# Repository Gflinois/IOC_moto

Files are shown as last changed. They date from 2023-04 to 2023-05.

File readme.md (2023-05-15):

# Motorcycle Sensor Network

This Git project contains the code for a network of sensors connected to a Raspberry Pi that collects data from a motorcycle and displays it on a webpage. The sensors include:

- thermistance for monitoring the heat of the engine
- lumistance for measuring light (by connecting a relay you can automate headlights)
- IMU for measuring acceleration and speed in all directions (interraction with website not ready yet because we have no non broken IMU yet)
- Tachimeter spying for RPM monitoring

The project also include an OLED output for ESP32, actually the esp32 used with the thermistance is receiving the lumistance value from the raspberry pi.

## Requirements

To use this code, you will need:

- Raspberry Pi 3 or later
- Python 3
- the python libraries shown in the dedicated file
- lumistance
- thermistance
- IMU sensor
- cables to divert the tachimeter's tension
- one esp32 by sensor with ble capability (exept for the IMU which's code is currently being developped for an arduino pro micro)

## Installation

1. Clone this Git repo's server file to your Raspi
2. Install the required Python packages on the Raspberry by running `pip3 install -r requirements.txt`
3. Install the BLE library on the ESPs (respectively arduino pro micro)
4. Install the driver for the correct sensor on the esp32s (respectively arduino pro micro)
5. Start the web server by running `python3 web.py`
6. Start the communication with the ESPs by using `python3 bleservice.py`

## Usage

After installing everything and instaling the sensors on the motorcycle , whatch the magic by connecting to the local server oppened by the raspberry.

### Contribution

Contributions to this Git project are welcome! Please submit pull requests to the `dev` branch and include a detailed description of your changes.

## License

This project is licensed under the MIT License. See the `LICENSE` file for details.

## Easter-egg for the ones that are working on a XJ400 (or that are having airbox issues)

Since airboxes are no longer available on the market for xj400 and as you may know this model is verry tightly packed I designed a 3D printable servicable low profile airbox in BAA. If anyone wants to build it please do, stl cad and gcode for an ender 3 pro are available. If anyone is interested in a simple airbox but for another model please try to modify my design and upload it here, I will be available to help you finish the work if need be.

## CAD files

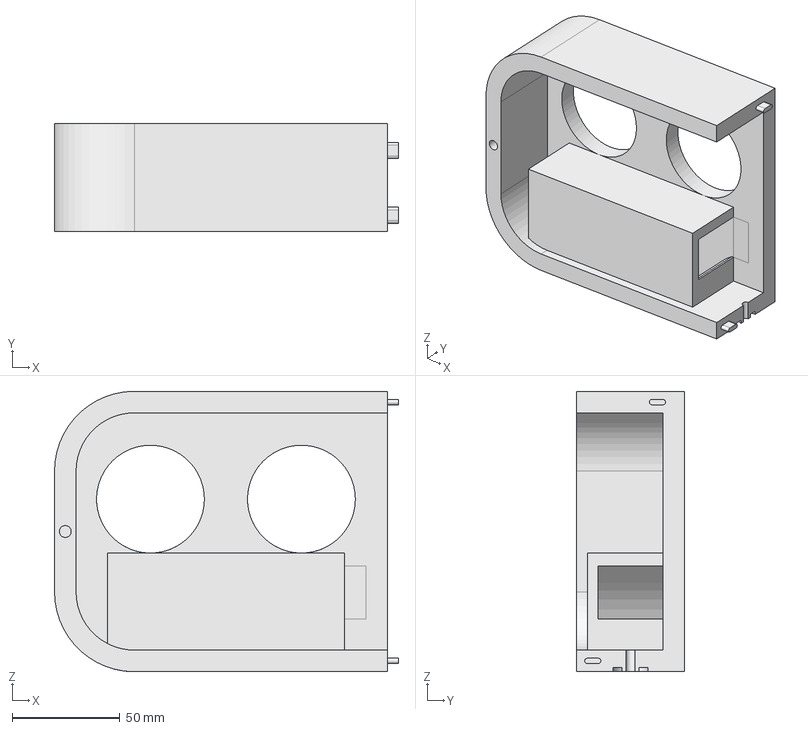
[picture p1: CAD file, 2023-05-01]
baa/cad/boite_a_air_L.FCStd
159.5 x 50.0 x 130.0 mm

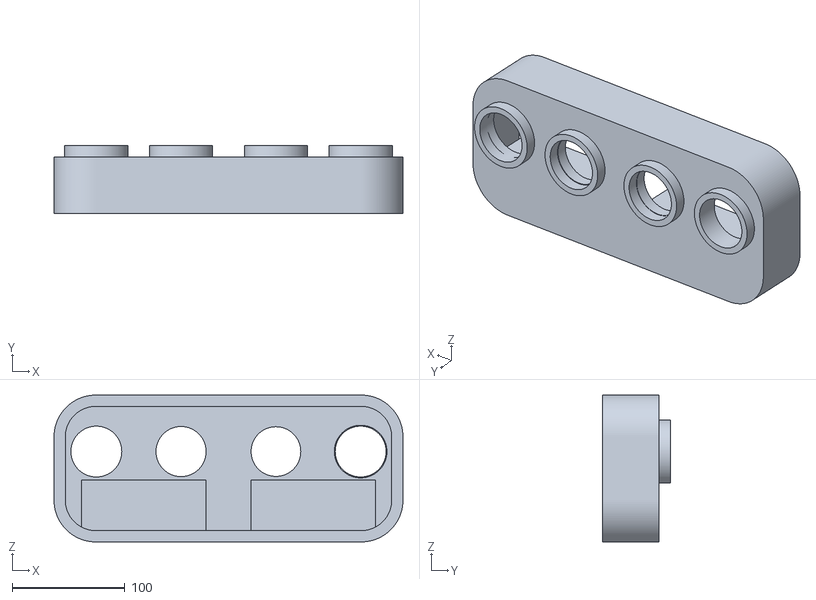
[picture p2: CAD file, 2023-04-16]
baa/stl/boite_a_air_tot.stl
309.0 x 60.0 x 130.0

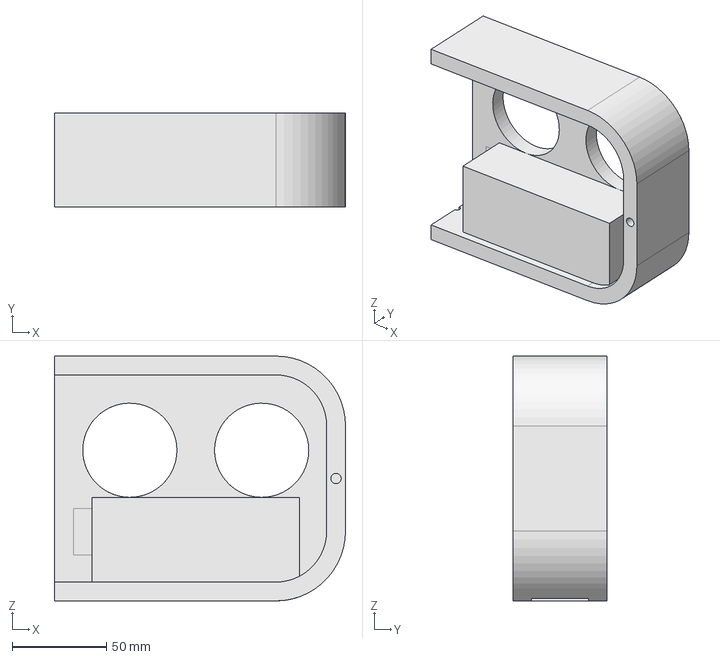
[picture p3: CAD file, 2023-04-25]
baa/cad/boite_a_air_R.FCStd
154.5 x 50.0 x 130.0 mm

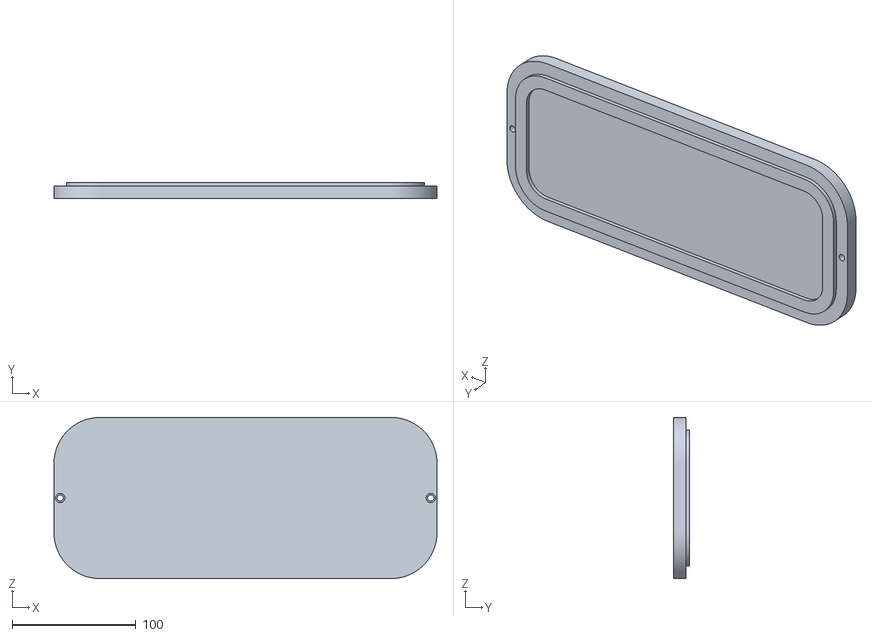
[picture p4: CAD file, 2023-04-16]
baa/stl/couvercle_tot.stl
309.0 x 13.0 x 130.0

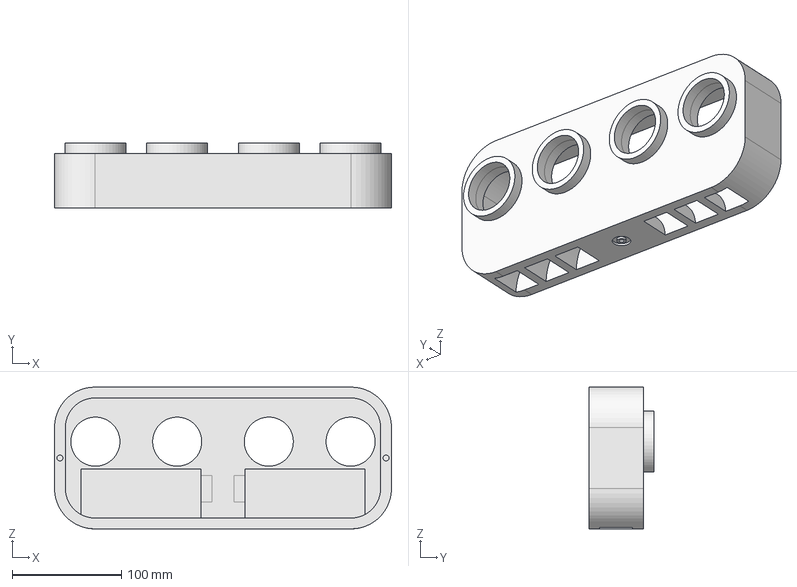
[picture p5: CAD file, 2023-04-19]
baa/cad/boite_a_air_thin.FCStd
309.0 x 60.0 x 130.0 mm

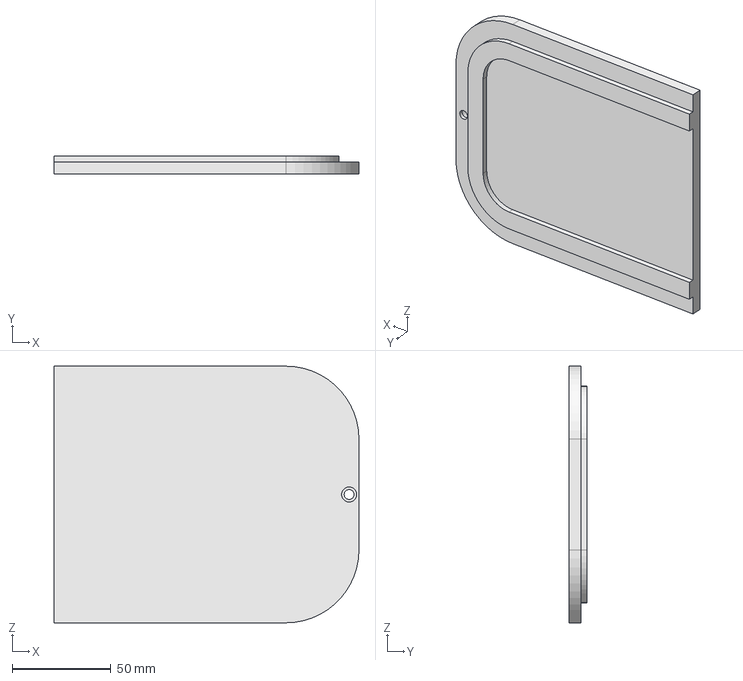
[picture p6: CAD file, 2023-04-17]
baa/cad/couvercle_R.FCStd
154.5 x 9.00 x 130.0 mm

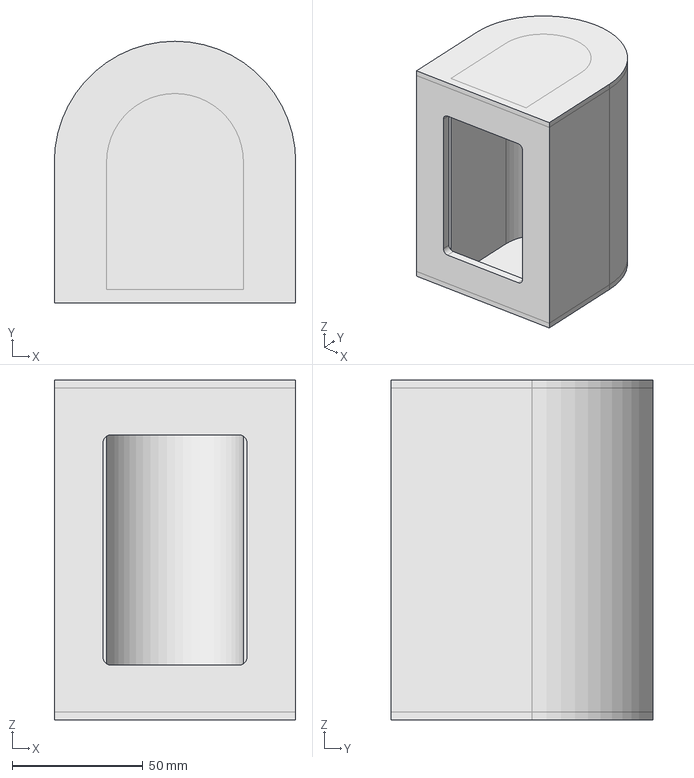
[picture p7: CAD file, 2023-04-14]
baa/cad/filtre.FCStd
92.3 x 100.0 x 130.0 mm

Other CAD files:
baa/cad/couvercle_L.FCStd
baa/cad/couvercle.FCStd
baa/stl/boite_a_air_L.stl
baa/stl/boite_a_air_R.stl
baa/stl/couvercle_L.stl
baa/stl/couvercle_R.stl

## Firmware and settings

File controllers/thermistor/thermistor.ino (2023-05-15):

#include <Adafruit_SSD1306.h>
#include <Adafruit_GFX.h>
#include <Wire.h>

#include <BLEDevice.h>
#include <BLEServer.h>
#include <BLEUtils.h>

// -----------------------------------------------------------------
// OLED CONFIG 
// -----------------------------------------------------------------

#define SCREEN_WIDTH 128 // OLED display width, in pixels
#define SCREEN_HEIGHT 64 // OLED display height, in pixels

#define OLED_RESET     16    // Reset pin # (or -1 if sharing Arduino reset pin)
#define SCREEN_ADDRESS 0x3C ///< See datasheet for Address; 0x3D for 128x64, 0x3C for 128x32

Adafruit_SSD1306 display(SCREEN_WIDTH, SCREEN_HEIGHT, &Wire, OLED_RESET);

// -----------------------------------------------------------------
// BLE CONFIG 
// -----------------------------------------------------------------

#define BLE_NAME                "MSN Thermistor"

// https://www.uuidgenerator.net/
#define TR_SERVICE_UUID         "0e4be5c8-b76c-4590-8eeb-35b93104c63e"
#define TR_CHARACTERISTIC_UUID  "177d03bb-a953-4f16-aabf-5246fbb3f72e"

#define PR_SERVICE_UUID         "f9e8c98a-0d57-423c-8ebc-ec69437c1c99"
#define PR_CHARACTERISTIC_UUID  "0dcdd589-bd02-42a5-b9c8-973ac9331c53"

#define THERMISTOR_PIN   36

char glbTrValue[32];
BLECharacteristic *glbTrCharacteristic;

char glbPrValue[32];
BLECharacteristic *glbPrCharacteristic;

bool deviceConnected = false;
bool advertising = false;

class ServerConnectCallback: public BLEServerCallbacks {
  void onConnect(BLEServer* pServer) {
    Serial.println("device connected");
    deviceConnected = true;
    advertising = false;
  };
  void onDisconnect(BLEServer* pServer) {
    Serial.println("device disconnected");
    deviceConnected = false;
  }
};

// -----------------------------------------------------------------
// TASK CONFIG 
// -----------------------------------------------------------------
#define MAX_WAIT_FOR_TIMER 2
unsigned int waitFor(int timer, unsigned long period){
  static unsigned long waitForTimer[MAX_WAIT_FOR_TIMER];  
  
  unsigned long newTime = micros() / period;
  int delta = newTime - waitForTimer[timer];
  
  if (delta < 0) 
    delta = 1 + newTime;
  
  if (delta)
    waitForTimer[timer] = newTime;
  
  return delta;
}

struct screen_refresh_s {
  int timer;
  int period;
};
struct screen_refresh_s screen_refresh_ctx;

void setup_screen_refresh(struct screen_refresh_s *ctx, int timer, int period) {
  ctx->timer = timer;
  ctx->period = period;
}

void loop_screen_refresh(struct screen_refresh_s *ctx) {
  if (!waitFor(ctx->timer, ctx->period)) return;
  Serial.println("screen refresh");
  if (deviceConnected) Serial.println("device connected: 1");
  else Serial.println("device connected: 0");
  if (advertising) Serial.println("advertising: 1");
  else Serial.println("advertising: 0");
  
  display.clearDisplay();
  display.setCursor(0, 0);

  display.println(BLE_NAME);
  display.println(F("BLE: on"));
  if (advertising)
    display.println(F("Status: advertising"));
  else
    display.println(F("Status: connected"));

  display.println();
  display.print("Lightning: ");
  display.print(glbPrCharacteristic->getValue().c_str());
  display.display();
}

// -----------------------------------------------------------------
// Main program 
// -----------------------------------------------------------------

void setup() {
  // ------------------------
  // Serial setup 
  // ------------------------
  Serial.begin(9600);
  Serial.println("starting ble services ...");

  // ------------------------
  // OLED setup 
  // ------------------------
  Wire.begin(4, 15);

  // SSD1306_SWITCHCAPVCC = generate display voltage from 3.3V internally
  if(!display.begin(SSD1306_SWITCHCAPVCC, SCREEN_ADDRESS)) {
    Serial.println(F("SSD1306 allocation failed"));
    for(;;); // Don't proceed, loop forever
  }
  display.clearDisplay();
  display.setTextSize(1);                     // Normal 1:1 pixel scale
  display.setTextColor(SSD1306_WHITE);        // Draw white text
  display.setCursor(0,0);                     // Start at top-left corner

  setup_screen_refresh(&screen_refresh_ctx, 0, 100000);

  // ------------------------
  // BLE setup 
  // ------------------------

  // Setup BLE peripheral (GATT server)
  BLEDevice::init(BLE_NAME);
  BLEServer *pServer = BLEDevice::createServer();
  pServer->setCallbacks(new ServerConnectCallback());
  BLEService *pRService = pServer->createService(TR_SERVICE_UUID);
  BLEService *pWService = pServer->createService(PR_SERVICE_UUID);
  
  // Initialize main characteristic (output)
  glbTrCharacteristic = pRService->createCharacteristic(
    TR_CHARACTERISTIC_UUID, BLECharacteristic::PROPERTY_READ);
  strncpy(glbTrValue, "0.0", 3);
  glbTrCharacteristic->setValue(glbTrValue);

  // Initialize secondary characteristic (input)
  glbPrCharacteristic = pWService->createCharacteristic(
    PR_CHARACTERISTIC_UUID, BLECharacteristic::PROPERTY_WRITE | BLECharacteristic::PROPERTY_READ);
  strncpy(glbPrValue, "?", 1);
  glbPrCharacteristic->setValue(glbPrValue);

  // Start the service
  pRService->start();
  pWService->start();
  
  // Setup & start ble ardvertising (pinging centrals)
  BLEAdvertising *pAdvertising = BLEDevice::getAdvertising();
  pAdvertising->addServiceUUID(TR_SERVICE_UUID);
  pAdvertising->addServiceUUID(PR_SERVICE_UUID);
  pAdvertising->setScanResponse(true);
  pAdvertising->setMinPreferred(0x06);
  pAdvertising->setMinPreferred(0x12);
  BLEDevice::startAdvertising();
  advertising = true;

  Serial.println("ble services started");

  // ------------------------
  // Hardware setup setup 
  // ------------------------
  
  // Setup the photoresistor
  pinMode(THERMISTOR_PIN, INPUT);

  display.display();
}

void loop() {
  if (deviceConnected) {
    int Vo;
    float R1 = 100000; // 10 kOhm
    float logR2, R2, T;
    float c1 = 1.009249522e-03, c2 = 2.378405444e-04, c3 = 2.019202697e-07;

    Vo = analogRead(THERMISTOR_PIN);
    R2 = R1 * (1023.0 / (float)Vo - 1.0);
    logR2 = log(R2);
    T = (1.0 / (c1 + c2*logR2 + c3*logR2*logR2*logR2));
    T = T - 273.15;
    T = (T * 9.0)/ 5.0 + 32.0; 

    // Update thermistor value (convert to string in order to debug)
    snprintf(glbTrValue, sizeof(glbTrValue), "%f", T);
    glbTrCharacteristic->setValue(glbTrValue);
  }

  if (!advertising && !deviceConnected) {
    BLEDevice::startAdvertising();
    advertising = true;
  }

  loop_screen_refresh(&screen_refresh_ctx);
}

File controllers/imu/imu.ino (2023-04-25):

#include <Wire.h>


//Gyro Variables
float elapsedTime, time, timePrev;        //Variables for time control
int gyro_error=0;                         //We use this variable to only calculate once the gyro data error
float Gyr_rawX, Gyr_rawY, Gyr_rawZ;     //Here we store the raw data read 
float Gyro_angle_x, Gyro_angle_y;         //Here we store the angle value obtained with Gyro data
float Gyro_raw_error_x, Gyro_raw_error_y; //Here we store the initial gyro data error

//Acc Variables
int acc_error=0;                         //We use this variable to only calculate once the Acc data error
float rad_to_deg = 180/3.141592654;      //This value is for pasing from radians to degrees values
float Acc_rawX, Acc_rawY, Acc_rawZ;    //Here we store the raw data read 
float Acc_angle_x, Acc_angle_y;          //Here we store the angle value obtained with Acc data
float Acc_angle_error_x, Acc_angle_error_y; //Here we store the initial Acc data error

float Total_angle_x, Total_angle_y;



void setup() {
  Wire.begin();                           //begin the wire comunication
  
  Wire.beginTransmission(0x68);           //begin, Send the slave adress (in this case 68)              
  Wire.write(0x6B);                       //make the reset (place a 0 into the 6B register)
  Wire.write(0x00);
  Wire.endTransmission(true);             //end the transmission
  //Gyro config
  Wire.beginTransmission(0x68);           //begin, Send the slave adress (in this case 68) 
  Wire.write(0x1B);                       //We want to write to the GYRO_CONFIG register (1B hex)
  Wire.write(0x10);                       //Set the register bits as 00010000 (1000dps full scale)
  Wire.endTransmission(true);             //End the transmission with the gyro
  //Acc config
  Wire.beginTransmission(0x68);           //Start communication with the address found during search.
  Wire.write(0x1C);                       //We want to write to the ACCEL_CONFIG register
  Wire.write(0x10);                       //Set the register bits as 00010000 (+/- 8g full scale range)
  Wire.endTransmission(true); 

  Serial.begin(9600);                     //Remember to set this same baud rate to the serial monitor  
  time = millis();                        //Start counting time in milliseconds


/*Here we calculate the acc data error before we start the loop
 * I make the mean of 200 values, that should be enough*/
  if(acc_error==0)
  {
    for(int a=0; a<200; a++)
    {
      Wire.beginTransmission(0x68);
      Wire.write(0x3B);                       //Ask for the 0x3B register- correspond to AcX
      Wire.endTransmission(false);
      Wire.requestFrom(0x68,6,true); 
      
      Acc_rawX=(Wire.read()<<8|Wire.read())/4096.0 ; //each value needs two registres
      Acc_rawY=(Wire.read()<<8|Wire.read())/4096.0 ;
      Acc_rawZ=(Wire.read()<<8|Wire.read())/4096.0 ;

      
      /*---X---*/
      Acc_angle_error_x = Acc_angle_error_x + ((atan((Acc_rawY)/sqrt(pow((Acc_rawX),2) + pow((Acc_rawZ),2)))*rad_to_deg));
      /*---Y---*/
      Acc_angle_error_y = Acc_angle_error_y + ((atan(-1*(Acc_rawX)/sqrt(pow((Acc_rawY),2) + pow((Acc_rawZ),2)))*rad_to_deg)); 
      
      if(a==199)
      {
        Acc_angle_error_x = Acc_angle_error_x/200;
        Acc_angle_error_y = Acc_angle_error_y/200;
        acc_error=1;
      }
    }
  }//end of acc error calculation   


/*Here we calculate the gyro data error before we start the loop
 * I make the mean of 200 values, that should be enough*/
  if(gyro_error==0)
  {
    for(int i=0; i<200; i++)
    {
      Wire.beginTransmission(0x68);            //begin, Send the slave adress (in this case 68) 
      Wire.write(0x43);                        //First adress of the Gyro data
      Wire.endTransmission(false);
      Wire.requestFrom(0x68,4,true);           //We ask for just 4 registers 
         
      Gyr_rawX=Wire.read()<<8|Wire.read();     //Once again we shif and sum
      Gyr_rawY=Wire.read()<<8|Wire.read();
   
      /*---X---*/
      Gyro_raw_error_x = Gyro_raw_error_x + (Gyr_rawX/32.8); 
      /*---Y---*/
      Gyro_raw_error_y = Gyro_raw_error_y + (Gyr_rawY/32.8);
      if(i==199)
      {
        Gyro_raw_error_x = Gyro_raw_error_x/200;
        Gyro_raw_error_y = Gyro_raw_error_y/200;
        gyro_error=1;
      }
    }
  }//end of gyro error calculation   
}//end of setup void






void loop() {
  timePrev = time;                        // the previous time is stored before the actual time read
  time = millis();                        // actual time read
  elapsedTime = (time - timePrev) / 1000; //divide by 1000 in order to obtain seconds

  //////////////////////////////////////Gyro read/////////////////////////////////////

    Wire.beginTransmission(0x68);            //begin, Send the slave adress (in this case 68) 
    Wire.write(0x43);                        //First adress of the Gyro data
    Wire.endTransmission(false);
    Wire.requestFrom(0x68,4,true);           //We ask for just 4 registers
        
    Gyr_rawX=Wire.read()<<8|Wire.read();     //Once again we shif and sum
    Gyr_rawY=Wire.read()<<8|Wire.read();
    /*Now in order to obtain the gyro data in degrees/seconds we have to divide first
    the raw value by 32.8 because that's the value that the datasheet gives us for a 1000dps range*/
    /*---X---*/
    Gyr_rawX = (Gyr_rawX/32.8) - Gyro_raw_error_x; 
    /*---Y---*/
    Gyr_rawY = (Gyr_rawY/32.8) - Gyro_raw_error_y;
    
    /*Now we integrate the raw value in degrees per seconds in order to obtain the angle
    * If you multiply degrees/seconds by seconds you obtain degrees */
    /*---X---*/
    Gyro_angle_x = Gyr_rawX*elapsedTime;
    /*---X---*/
    Gyro_angle_y = Gyr_rawY*elapsedTime;


    
  
  //////////////////////////////////////Acc read/////////////////////////////////////
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

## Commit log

2023-03-29 askip j'ai oublié de mettre le cite la semaine dernière lol
    [data.csv]
2023-04-14 add imu
2023-04-14 j'ad la boite à air lol
    [assemblage.FCStd, boite à air.FCStd, couvercle.FCStd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]
2023-04-15 ajout de la symatrie et recréation des fillets
    [boite à air.FCStd]
2023-04-16 préparation pour l'impression : exportation en stl, création du gcode pour une piece de chaque, coupage en 2 car trop gros pour l'impression en une pièce et remise à plus tard de l'impression de la b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
    [boite à air.FCStd, boite_a_air_L.FCStd, boite_a_air_L.stl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]
2023-04-17 je range toute ce bordel et thinning des murs
    [assemblage.FCStd, boite_a_air_L.FCStd, boite_a_air_L.stl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]
2023-04-19 réparé le pb de fit et recréation des Gcodes go print lol
    [boite_a_air_L.FCStd, boite_a_air_L.stl, boite_a_air_R.FCStd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]
2023-04-20 correction du rayon d'ouverture pour les caoutchoux, enlevage des protrusion d'accroches (trop chiant à imprimer et inutile avec les nouveaux caoutchoux)
    [boite_a_air_L.FCStd, boite_a_air_L.stl, boite_a_air_R.FCStd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]
2023-04-20 gcode de la modif
2023-04-20 added ble communication
    [data.csv, dummy.csv]
2023-04-25 lightning c'est incroyable
    [boite_a_air_L.FCStd, boite_a_air_L.stl, boite_a_air_R.FCStd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]
2023-04-25 stp git arrête de faire n'imp
    [boite_a_air_L.FCStd, boite_a_air_L.stl]
2023-05-01 minor changes in the airbox
    [boite_a_air_L.FCStd]
2023-05-02 server dynamic moche qui fonctionne sur raspi
    [dummy.csv]
2023-05-15 [controllers] added a thermistor controller
